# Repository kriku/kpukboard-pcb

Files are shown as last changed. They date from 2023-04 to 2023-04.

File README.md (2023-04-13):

# kpukboard-pcb
Bluetooth keyboard - printed circuit board design

kpukboard is a 38 key column-staggered choc split keyboard

it meant to be used with a [seeeduino xiao ble](https://wiki.seeedstudio.com/XIAO_BLE/)

as thin as possible with kailh choc mini switches

BOM:
- kailh choc switch mini - 38 pcs
- kailh choc keycap - 38 pcs
- seeeduino xiao ble - 2 pcs
- sod-123 diodes - 38 pcs
- pcb-7 welding terminals m3 - 4 pcs 
- m3 screw 6mm - 4 pcs
- battery 603030 - 2 pcs
- mss-22d18 power switches - 2 pcs
- silicone rubber pad 1mm - 2 pcs

[build process](https://t.me/kpukboard)

left
right
pcb design
schematic

inspired by [TOTEM](https://github.com/GEIGEIGEIST/TOTEM)

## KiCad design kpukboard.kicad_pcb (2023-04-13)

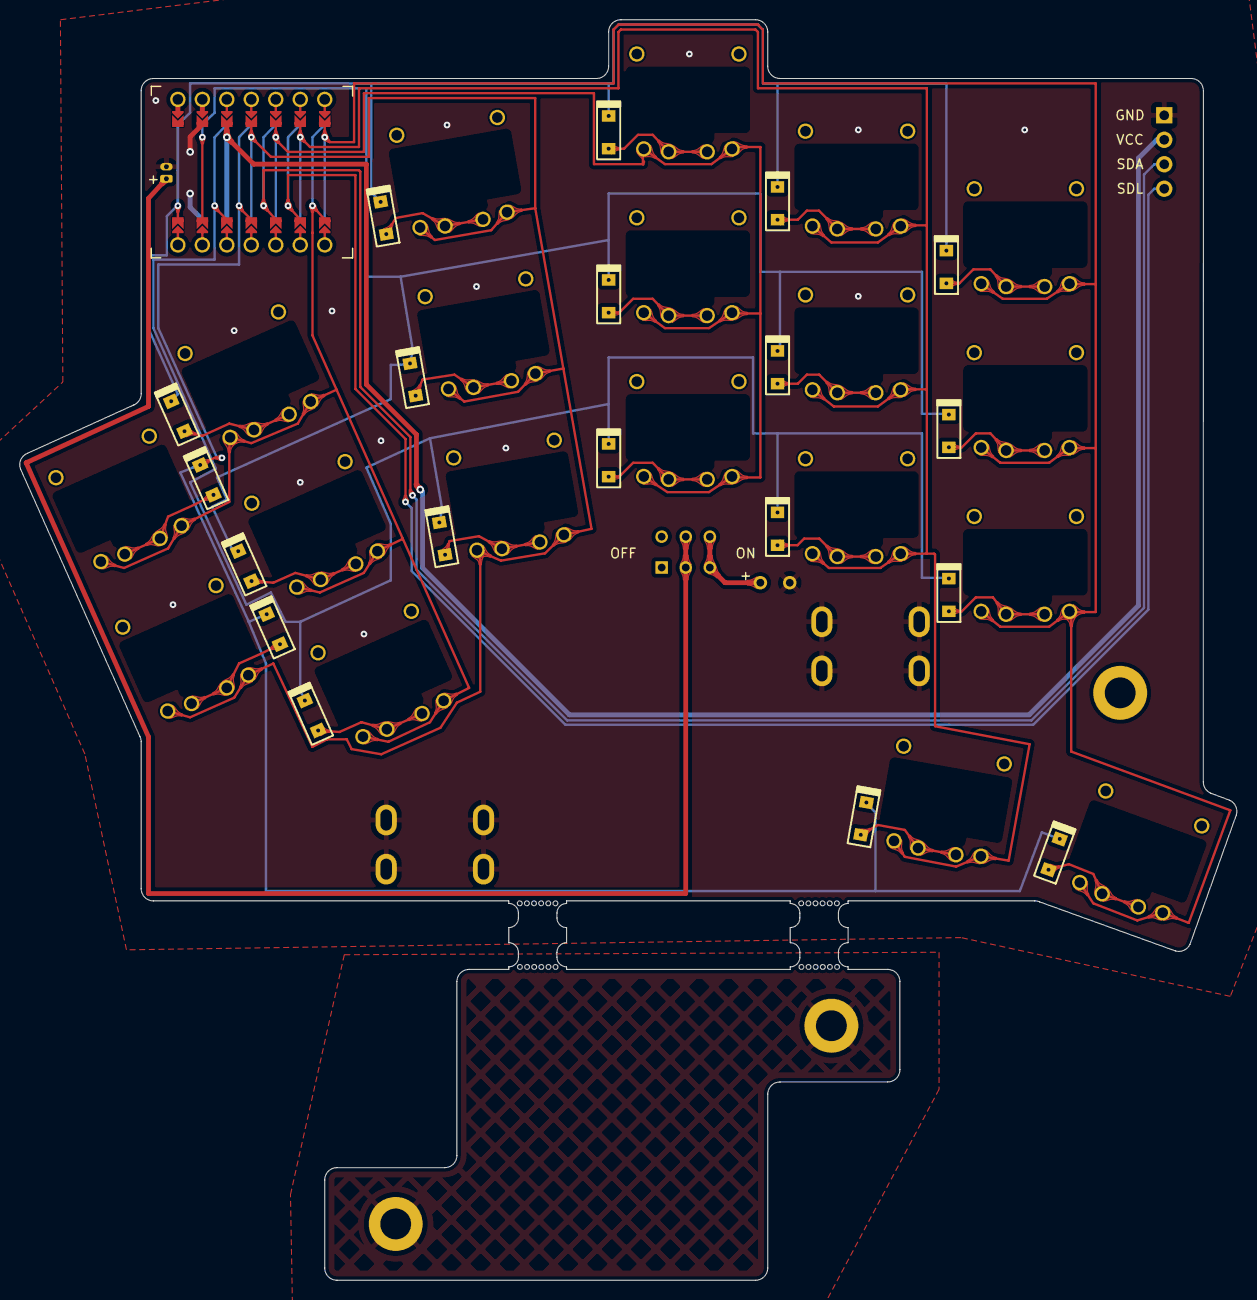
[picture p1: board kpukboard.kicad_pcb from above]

Board: 2 copper layers, 126.3 x 130.8 mm, 48 parts (0 on the bottom side), 34 nets.

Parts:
D1, D2, D3, D4, D5, D6, D7, D8, D9, D10, D11, D12, D13, D14, D15, D16, D17, D18, D19: D_Small; Diode_SOD123_THT_2
H1, H2: MountingHole_Pad; pcb7xm3
H3, H4, H5: MountingHole_Pad; MountingHole_3.2mm_M3_DIN965_Pad
J1: Conn_01x02_Female; battery-pad
J2: Conn_01x02_Female; Molex_PicoBlade_53048-0210_1x02_P1.25mm_Horizontal
J3: Conn_01x04_Male; PinHeader_1x04_P2.54mm_Vertical
PSW1: SW_SPDT; SW_MS-22D18G2ROHS
SW1, SW2, SW3, SW4, SW5, SW6, SW7, SW8, SW9, SW10, SW11, SW12, SW13, SW14, SW15, SW16, SW17, SW18, SW19: SW_Push_45deg; Kailh_PG1232_reversible
U1: xiao-ble; Xiao THT jumper pad

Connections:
BAT+: J2.1, PSW1.2 (B)
GND: H1.1, H2.1, H3.1, H4.1, J1.2, J2.2, J3.1, U1.13 (GND)
unnamed: D1.2 (A), SW1.2
unnamed: D2.2 (A), SW2.2
unnamed: D3.2 (A), SW3.2
unnamed: D4.2 (A), SW4.2
unnamed: D5.2 (A), SW5.2
unnamed: D6.2 (A), SW6.2
unnamed: D7.2 (A), SW7.2
unnamed: D8.2 (A), SW8.2
unnamed: D9.2 (A), SW9.2
unnamed: D10.2 (A), SW10.2
unnamed: D11.2 (A), SW11.2
unnamed: D12.2 (A), SW12.2
unnamed: D13.2 (A), SW13.2
unnamed: D14.2 (A), SW14.2
unnamed: D15.2 (A), SW15.2
unnamed: D16.2 (A), SW16.2
unnamed: D17.2 (A), SW17.2
unnamed: D18.2 (A), SW18.2
unnamed: D19.2 (A), SW19.2
VBAT: J1.1, PSW1.3 (C)
VCC: J3.2, U1.12 (3V3)
col0: SW1.1, SW6.1, SW11.1, SW16.1, U1.7 (B8_TX/1.11)
col1: SW2.1, SW7.1, SW12.1, SW17.1, U1.11 (A6_MOSI/1.15)
col2: SW3.1, SW8.1, SW13.1, U1.10 (A5_MISO/1.14)
col3: SW4.1, SW9.1, SW14.1, SW18.1, U1.9 (A7_SCK/1.13)
col4: SW5.1, SW10.1, SW15.1, SW19.1, U1.8 (B9_RX/1.12)
row0: D1.1 (K), D2.1 (K), D3.1 (K), D4.1 (K), D5.1 (K), U1.1 (A2/0.02_H)
row1: D6.1 (K), D7.1 (K), D8.1 (K), D9.1 (K), D10.1 (K), U1.2 (A4/0.03_H)
row2: D11.1 (K), D12.1 (K), D13.1 (K), D14.1 (K), D15.1 (K), U1.3 (A10/0.28)
row3: D16.1 (K), D17.1 (K), D18.1 (K), D19.1 (K), U1.4 (A11/0.29)
sda: J3.3, U1.5 (A8_SDA/0.04_H)
sdl: J3.4, U1.6 (A9_SCL/0.05_H)
